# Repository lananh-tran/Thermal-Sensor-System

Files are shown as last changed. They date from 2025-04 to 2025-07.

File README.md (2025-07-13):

# Thermal Sensor System

by Lan-Anh Tran

_Many thanks to Carter Trudeau and Kyle Chen for their help in this project._

## Introduction

We are part of the [Chico Rocketry and Aerospace Club](https://www.instagram.com/chicorocketry/) at California State University, Chico. This is the documentation of one of our electronic modules for our rocket - the Wildcat V, which our team brought to [IREC 2025](https://www.herox.com/IREC2025) (International Rocket Engineering Competition). The purpose of this module is to take measurements of the surrounding ambient temperature and inner surface temperature of the rocket before and during flight for simulation purposes. The components used in this project can be viewed in the [Bill of Materials](https://github.com/lananh-tran/Thermal-Sensor-System/blob/1d724febd7ca4944d8594dc0ccbd3dcf55217213/Thermal%20Sensor%20System%20BOM%202025.xlsx) or shown below:

- [Adafruit MAX31865 PT100 RTD Temperature Sensor Amplifier](https://www.adafruit.com/product/3328)
- [Adafruit MCP9808 I2C Temperature Sensor Breakout Board](https://www.adafruit.com/product/1782)
- [MPU6050 Analog Gyro Sensors and Accelerometer Module](https://www.amazon.com/Gy-521-MPU-6050-MPU6050-Sensors-Accelerometer/dp/B008BOPN40?sr=8-2)
- [HiLetgo Micro SD TF Card Adapter Reader Module](https://www.amazon.com/HiLetgo-Adater-Interface-Conversion-Arduino/dp/B07BJ2P6X6?sr=8-1)
- [Battery Charger Module](https://www.amazon.com/dp/B098989NRZ?amp=&amp=)
- [Samsung 35E 18650 3500mAh 8A - Button Top Battery](https://www.18650batterystore.com/products/samsung-35e-button-top)
- [Arduino Nano Microcontroller](https://www.amazon.com/LAFVIN-Board-ATmega328P-Micro-Controller-Arduino/dp/B07G99NNXL?sr=8-1)
- [Surface Mount RTD PT100 Temperature Sensor](https://evosensors.com/products/p3a-tape-rec-px-1-pfxx-40-stwl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)

Link to the KiCad [schematic](https://github.com/lananh-tran/Thermal-Sensor-System/blob/4369b679e1e1e8256428873dc583f430bf157983/Thermal-System.kicad_sch) and [PCB layout](https://github.com/lananh-tran/Thermal-Sensor-System/blob/4369b679e1e1e8256428873dc583f430bf157983/Thermal-System.kicad_pcb) files.

## Design Procedure

Below is the rough design for the sensor system. See [design schematic](https://github.com/lananh-tran/Thermal-Sensor-System/blob/db7faa17b55e4ecaf4507a09ca1c67294a6be1d8/Thermal%20System%20Schematic.pdf) and [PCB layout](https://github.com/lananh-tran/Thermal-Sensor-System/blob/db7faa17b55e4ecaf4507a09ca1c67294a6be1d8/Thermal%20System%20PCB.pdf) for more details.

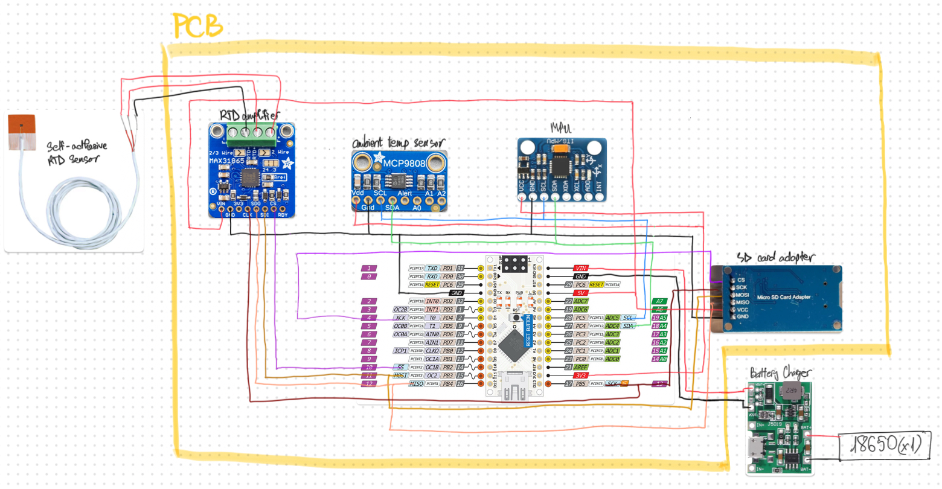
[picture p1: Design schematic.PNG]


Except for the RTD sensor, the battery charger module, and the 18650 battery, the rest are mounted on a PCB.

The MCP9808 and the MPU6050 both utilize the I2C communication protocol, while the MAX31865 and the microSD Card Adapter use the SPI protocol. Though we couldn't find a particular reason why there aren't any I2C breakout boards for the MAX31865, we assume the microSD Card Adapter has to use SPI due to its need for speed. This resulted in a communication issue, which will be discussed in the Results section.

I2C devices communicate through two lines - the clock (SCL) and the data line (SDA). An I2C master can be connected to different slaves, as long as their SDA lines are connected and their SCL lines are connected.

SPI devices require more connections, with a clock line (SCK or CLK), Master-In-Slave-Out (MISO or SDO), Master-Out-Slave-In (MOSI or SDI), and a Chip Select line (CS). Multiple SPI slaves can have their CLK, MISO, and MOSI lines connected to the corresponding lines of their master, but each slave has to be connected to a different CS pin on their master.

In order to mitigate the potential wiring errors, we opt to design and fabricate a custom PCB of size 6 x 1.6 in, with a drill hole diameter of 0.1 in. The design is done in KiCad, which is a powerful and free PCB design software. KiCad also allows 3D modelling, which is quite convenient if you want to make sure the electrical design is compatible with the mechanical structure.

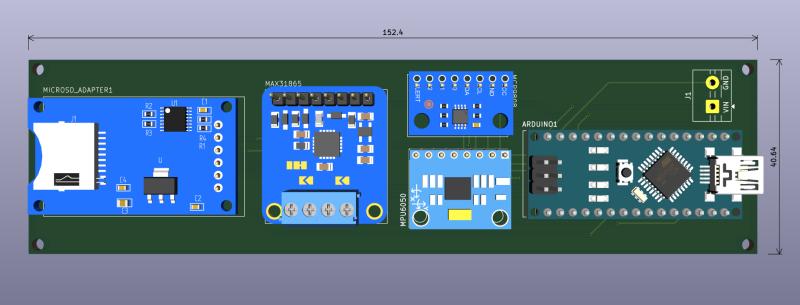
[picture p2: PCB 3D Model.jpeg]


## Assembly Process

The assembly process is quite straightforward. After soldering all the components onto the PCB, connect the RTD sensor to the MAX31865 breakout board as shown below, then connect the battery and charger module as demonstrated in the system schematic posted above.

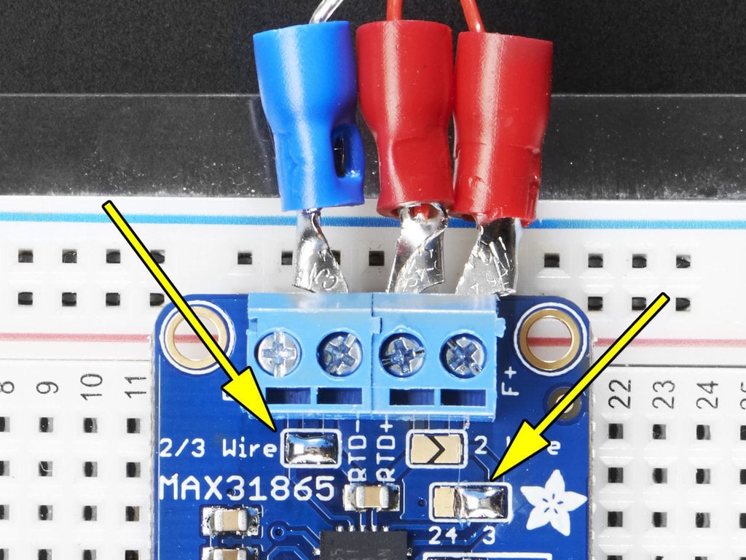
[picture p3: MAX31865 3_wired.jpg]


More details about the MAX31865 wiring can be viewed on [Adafruit's official guide](https://learn.adafruit.com/adafruit-max31865-rtd-pt100-amplifier/rtd-wiring-config).

## Results

We chose [OSH Park](https://oshpark.com/) to fabricate our PCB as they are a US-based company, thereby having a lower shipping cost.

Below is the final product before it was sent to IREC 2025 for competition:

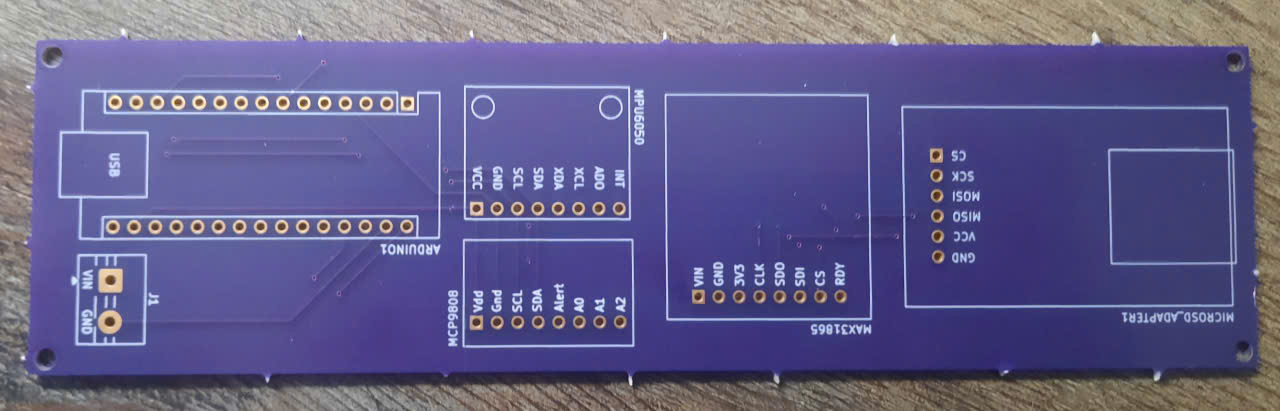
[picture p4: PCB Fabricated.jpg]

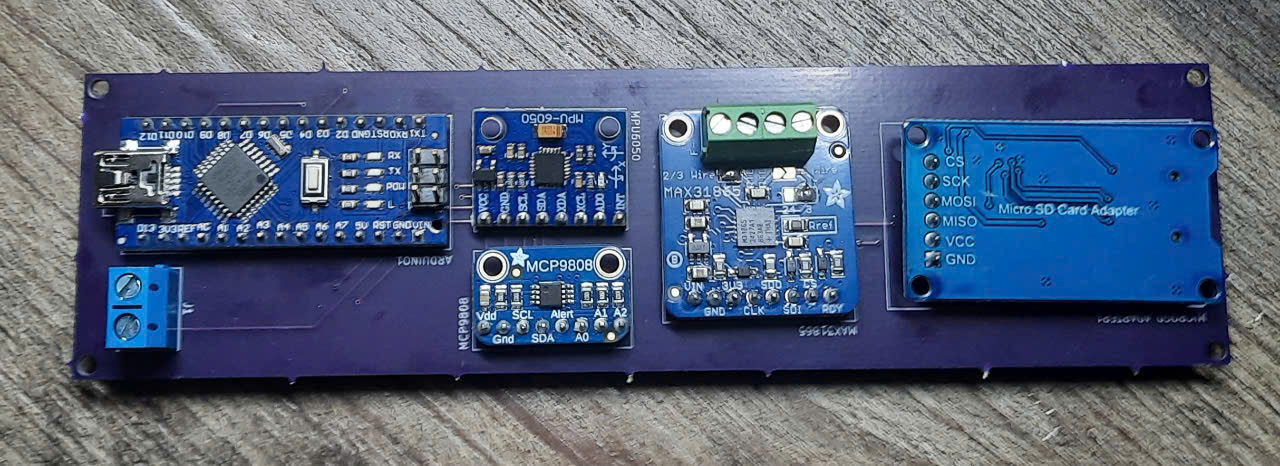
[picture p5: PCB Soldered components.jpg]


A critical issue we have with this module is the design of the microSD Adapter Module, which leads to the SPI bus not getting off the SPI bus. As a result, we initially couldn't implement multiple SPI devices using a single Arduino. To debug, we opted to utilize the logic analyzer function of the ADALM2000 module to observe the behavior of the system.

Results when the SD module is connected:
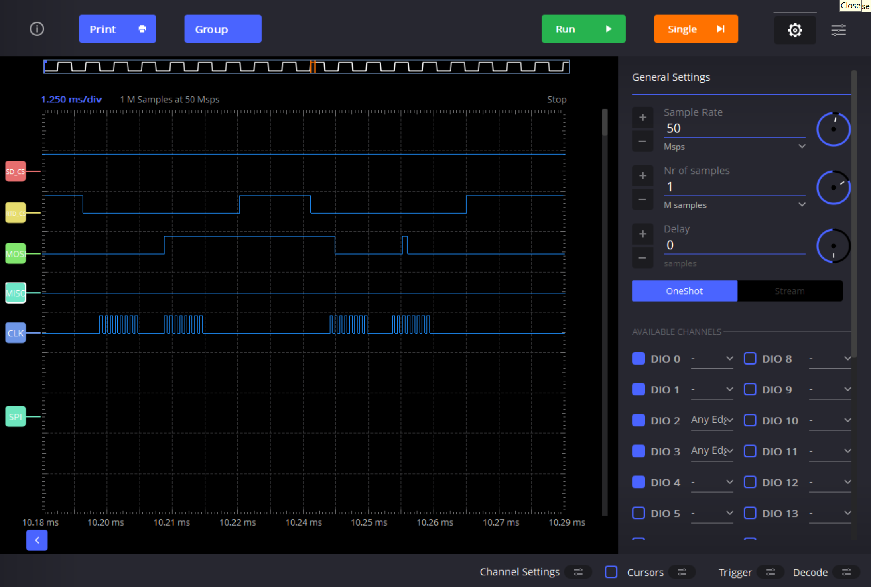
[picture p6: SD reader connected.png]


When the SD module isn't connected:
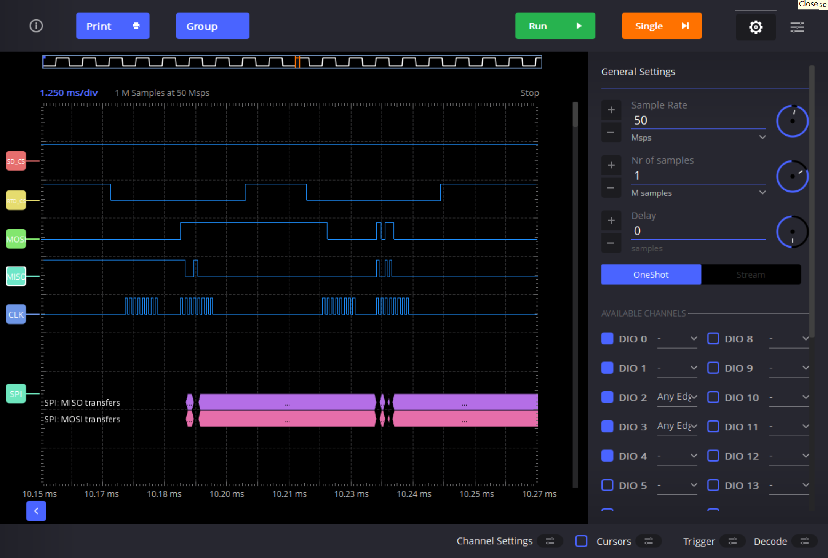
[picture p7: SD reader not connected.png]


After a close inspection of the SD module schematic, we suspect that the MISO might be pulled to GND by default by the buffer, leading to the issue with the SPI bus.
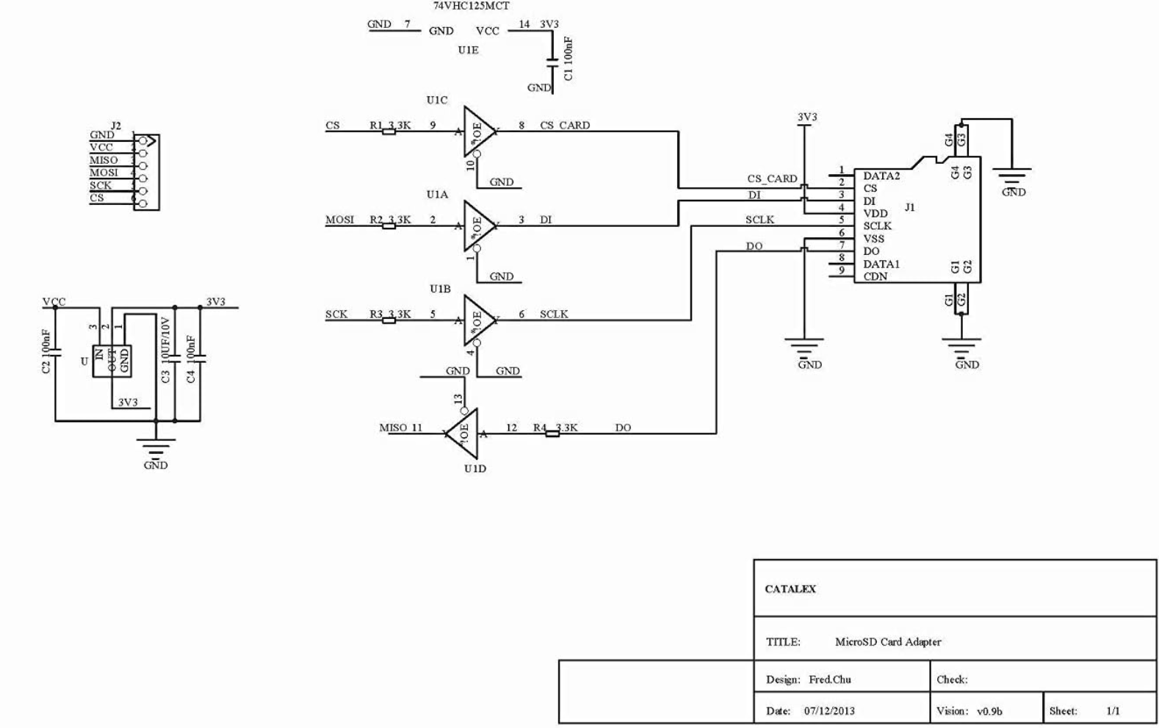
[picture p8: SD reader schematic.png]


We decided to follow a modification suggested on the Arduino Forum (source lost), as shown below.
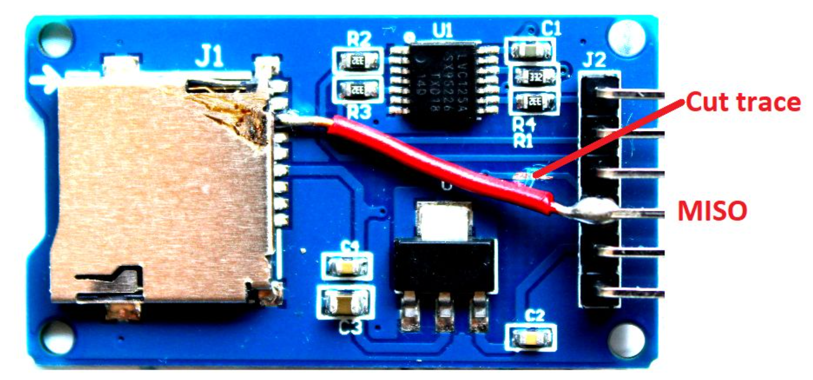
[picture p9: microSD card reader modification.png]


Our modified SD module works properly when connected to the system along with the MAX31865 amplifier.

## Code

```
#include <SPI.h>
#include <Wire.h>
#include <SD.h>
#include <Adafruit_MPU6050.h>
#include <Adafruit_Sensor.h>
#include <Adafruit_MCP9808.h>
#include <Adafruit_MAX31865.h>

// --- CONFIGURATION ---
int timeStamp = 1;
#define SD_CS 4
//SdFat SD;
File dataLog;

float acceleration;
Adafruit_MPU6050 mpu;

float ambient;
Adafruit_MCP9808 ambientTemp = Adafruit_MCP9808();

#define RREF 430.0 // Rref resistor for PT100
#define RNOMINAL 100.0 // Nominal resistance for PT100
#define RTD_CS 10
#define MOSI 11
#define MISO 12
#define CLK 13
float surface;
Adafruit_MAX31865 surfaceTemp = Adafruit_MAX31865(RTD_CS);

void setup() {
  // set serial monitor baud rate
  Serial.begin(9600);
  while(!Serial) {;}

  // MCP9808 initialization
  MCP_init();

  // MPU6050 initialization
  MPU_init();

  // SD card initialization
  SD_init();

  // MAX31865 initialization
  pinMode(RTD_CS, OUTPUT);
  digitalWrite(RTD_CS, HIGH);
  surfaceTemp.begin(MAX31865_3WIRE);
  delay(1000);

  // SPI communication setup
  SPI.begin();

  Serial.println("Begin testing:");
}

void loop() {
  // --- MCP9808 Sampling ---
  MCP_sample();

  // testing
  Serial.print("Ambient temp: "); 
  Serial.print(ambient, 3);
  Serial.println("*C");

  // --- MAX31865 Sampling ---
  MAX_sample();

  // testing
  Serial.print("Surface temp: "); 
  Serial.print(surface, 3);
  Serial.println("*C");

  // --- MPU6050 Sampling ---
  MPU_sample();

  // testing
  Serial.print("Acceleration: "); 
  Serial.print(acceleration, 3);
  Serial.println("m/s^2");

  // --- SD card reader ---
  SD_write();

  delay(1000); // take readings every 1s
}

void MCP_init(void) {
  //  A2 A1 A0 address
  //  0  0  0   0x18  this is the default address
  //  0  0  1   0x19
  //  0  1  0   0x1A
  //  0  1  1   0x1B
  //  1  0  0   0x1C
  //  1  0  1   0x1D
  //  1  1  0   0x1E
  //  1  1  1   0x1F
  if(!ambientTemp.begin(0x18)) {
	  Serial.println("Unable to connect to the MCP9808!");
	  Serial.println("Check your connections and verify the address is correct.");
	  while (1);
  }

  // Mode Resolution SampleTime
  //  0    0.5°C       30 ms
  //  1    0.25°C      65 ms
  //  2    0.125°C     130 ms
  //  3    0.0625°C    250 ms
  ambientTemp.setResolution(3);
  //Serial.println("MCP9808 initialized!");
  delay(1000); // Give sensor time to stabilize
}

void MPU_init(void) {
  if (!mpu.begin()) {
    Serial.println("Failed to find MPU6050 chip");
    while (1);
  }

  mpu.setAccelerometerRange(MPU6050_RANGE_16_G);
  mpu.setGyroRange(MPU6050_RANGE_500_DEG);
  mpu.setFilterBandwidth(MPU6050_BAND_21_HZ);

  delay(1000); // Give sensor time to stabilize
}

void SD_init(void) {
  pinMode(SD_CS, OUTPUT);
  digitalWrite(SD_CS, HIGH);
  //Serial.println("Initializing SD card...");
  if(!SD.begin(SD_CS)) {
    Serial.println("SD card initialization failed!");
    //while(1) {;}
  }
  //Serial.println("Card initialized!");

  dataLog = SD.open("DATALOG.csv", FILE_WRITE);
  if(!dataLog) {
    Serial.println("Failed to write!");
    //while(1) {;}
  }
  dataLog.println("no.,ambientTemp(C),surfaceTemp(C),acceleration(m/s^2)");
}

void MCP_sample(void) {
  ambientTemp.wake();
  delay(200);
  ambient = ambientTemp.readTempC();
  ambientTemp.shutdown_wake(1);
  delay(200);
}

void SD_write(void) {
  digitalWrite(RTD_CS, HIGH);
  digitalWrite(SD_CS, LOW);
  
  if(dataLog) {
    dataLog.print(timeStamp);
    dataLog.print(",");
    dataLog.print(ambient, 3);
    dataLog.print(",");
    dataLog.print(surface, 3);
    dataLog.print(",");
    dataLog.println(acceleration, 3);
    
    dataLog.flush();
    delay(200);
  }

  digitalWrite(SD_CS, HIGH);
  timeStamp++;
  Serial.println("Writing done");
}

void MAX_sample(void) {
  digitalWrite(SD_CS, HIGH);
  digitalWrite(RTD_CS, LOW);
  surface = surfaceTemp.temperature(RNOMINAL, RREF);
  delay(200);
  digitalWrite(RTD_CS, HIGH);
}

void MPU_sample(void) {
  // Get new sensor events with the readings
  sensors_event_t a, g, temp;
  mpu.getEvent(&a, &g, &temp);
  acceleration = sqrt(a.acceleration.x * a.acceleration.x +
                        a.acceleration.y * a.acceleration.y +
                        a.acceleration.z * a.acceleration.z) - 9.81; // account for Earth stationary acceleration
}
```

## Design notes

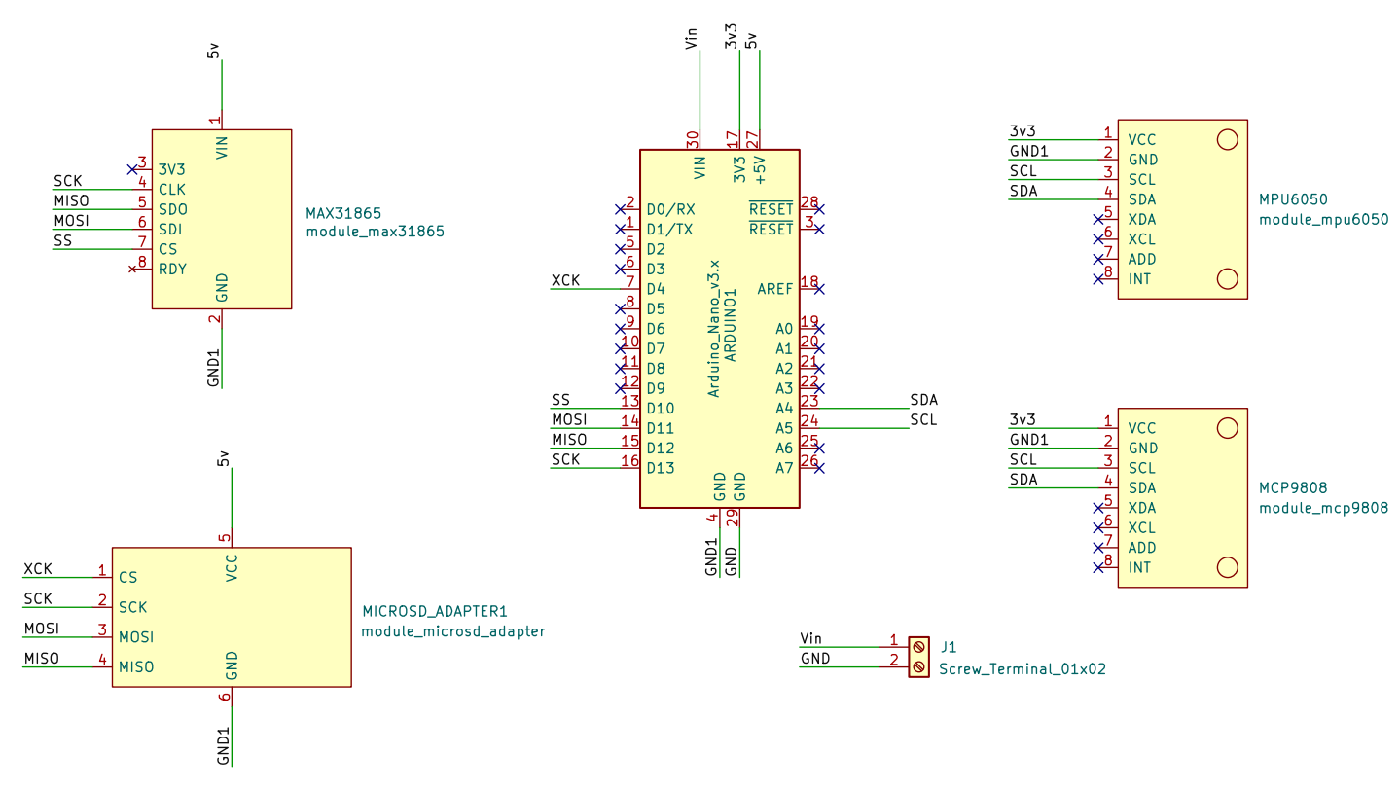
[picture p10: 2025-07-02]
KiCad Schematic.png

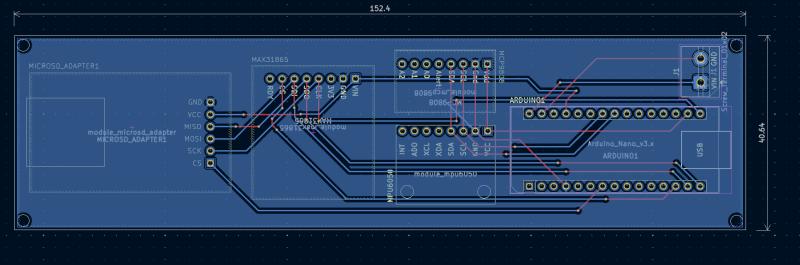
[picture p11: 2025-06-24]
PCB Layout.jpeg

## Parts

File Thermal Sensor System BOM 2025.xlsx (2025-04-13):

Website | Item | Cost per unit | Quantity | Total | Description | Link | Datasheet | Dimensions
18650 Battery Store | Samsung 35E 18650 3500mAh 8A - Button Top Battery | $9.99 | 1 | $9.99 |  | https://www.18650batterystore.com/products/samsung-35e-button-top
 |  |  | Local total | $9.99
Amazon | Battery Charger Module 6pcs | $9.89 | 1 | $9.89 |  | https://www.amazon.com/dp/B098989NRZ?ref_=cm_sw_r_cso_cp_apan_dp_P1GT6V82NTPXW35JH8QN&previewDoh=1
 | Arduino Nano 3pcs | $15.99 | 1 | $15.99 |  | https://www.amazon.com/ELEGOO-Pre-soldered-ATmega-Compatible-Arduino/dp/B0D5LYFRQP?sr=8-2 | https://www.nitrathor.com/data-sheets/arduino-nano | 43.16 mm x 17.76 mm x 2.54 mm
 | MPU-6050 Axis Accelerometer Gyroscope Sensor Module 5pcs | $14.99 | 1 | $14.99 |  | https://www.amazon.com/MPU-6050-MPU6050-Accelerometer-Gyroscope-Converter/dp/B07RXQGGJX?sr=8-18
 | Hiletgo Micro SD Card Reader Module 5pcs | $6.99 | 1 | $6.99 |  | https://www.amazon.com/HiLetgo-Adater-Interface-Conversion-Arduino/dp/B07BJ2P6X6?sr=8-1 | http://datalogger.pbworks.com/w/file/fetch/89507207/Datalogger%20-%20SD%20Memory%20Reader%20Datasheet.pdf | ‎76.2 x 58.4 x 10.2 mm
 |  |  | Local total | $47.86
Adafruit | MCP9808 Temperature Sensor Breakout Board | $4.95 | 1 | $4.95 |  | https://www.adafruit.com/product/1782 | https://cdn-shop.adafruit.com/datasheets/MCP9808.pdf | 21mm x 13mm x 2mm / 0.8" x 0.5" x 0.08
 |  |  | Local total | $4.95
Digikey | PT100 RTD Temperature Sensor Amplifier - MAX31865 | $14.95 | 1 | $14.95 |  | https://www.digikey.com/en/products/detail/adafruit-industries-llc/3328/6562952 | https://www.analog.com/media/en/technical-documentation/data-sheets/max31865.pdf | 28.0mm x 25.5mm x 3.0mm / 1.1" x 1.0" x 0.1
 |  |  | Local total | $14.95
Evolution | Surface Mount PT100 RTD Temperature Sensor | $45.00 | 1 | $45.00 |  | https://evosensors.com/products/p3a-tape-rec-px-1-pfxx-40-stwl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 | https://cdn.shopify.com/s/files/1/1679/4593/files/P3A-TAPE-REC-PX-1-PFXX-40-STWL-specsheet.pdf?v=1649167083 | 25mm x 19mm (patch)
 |  |  | Local total | $45.00
 |  |  | Grand total | $112.76

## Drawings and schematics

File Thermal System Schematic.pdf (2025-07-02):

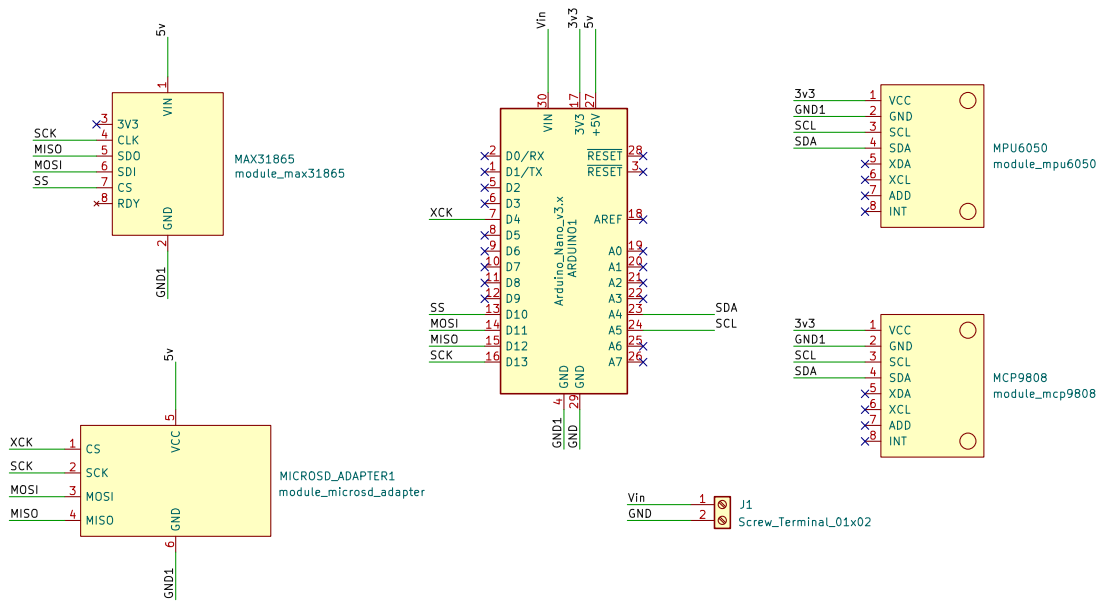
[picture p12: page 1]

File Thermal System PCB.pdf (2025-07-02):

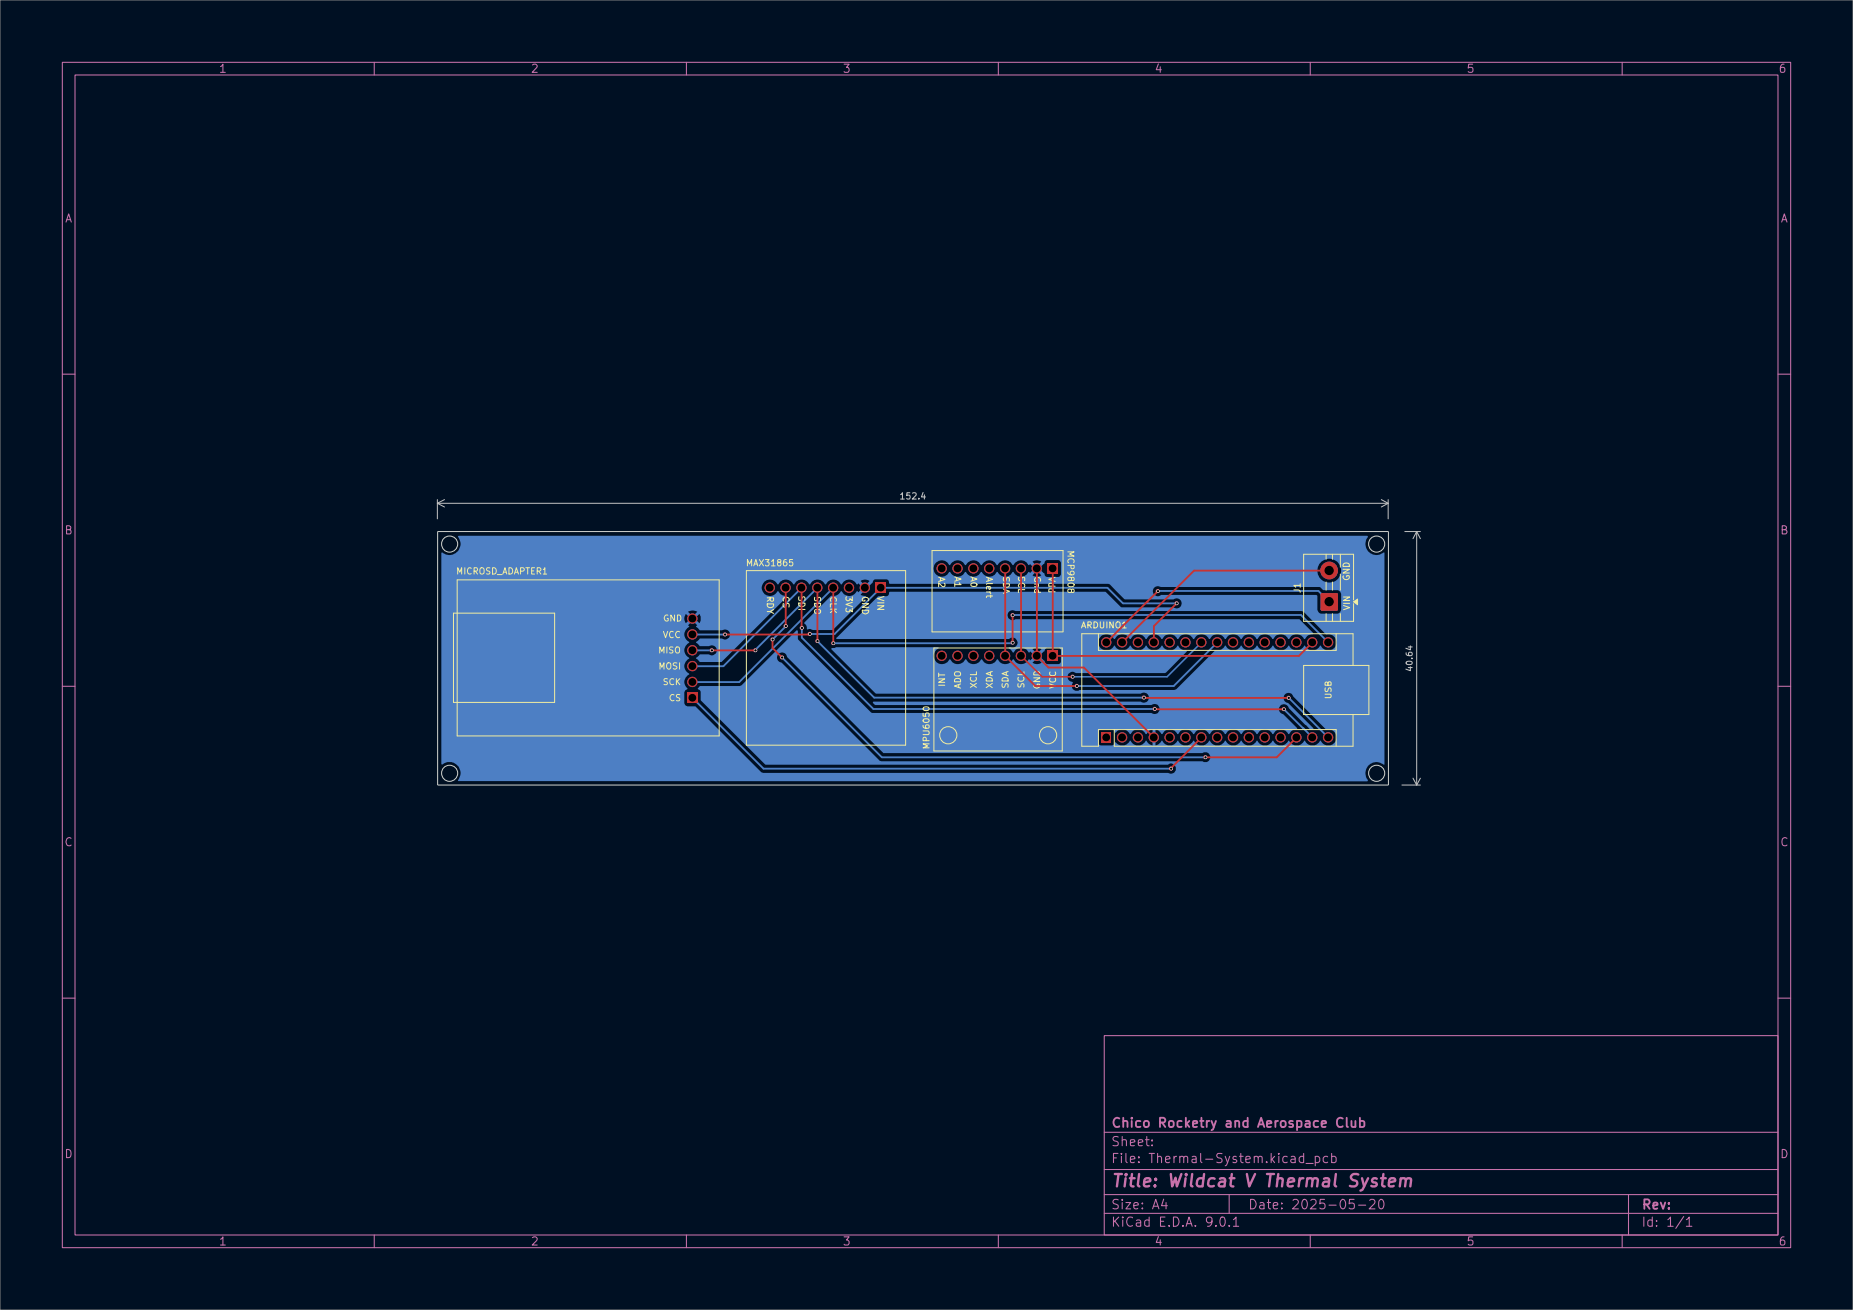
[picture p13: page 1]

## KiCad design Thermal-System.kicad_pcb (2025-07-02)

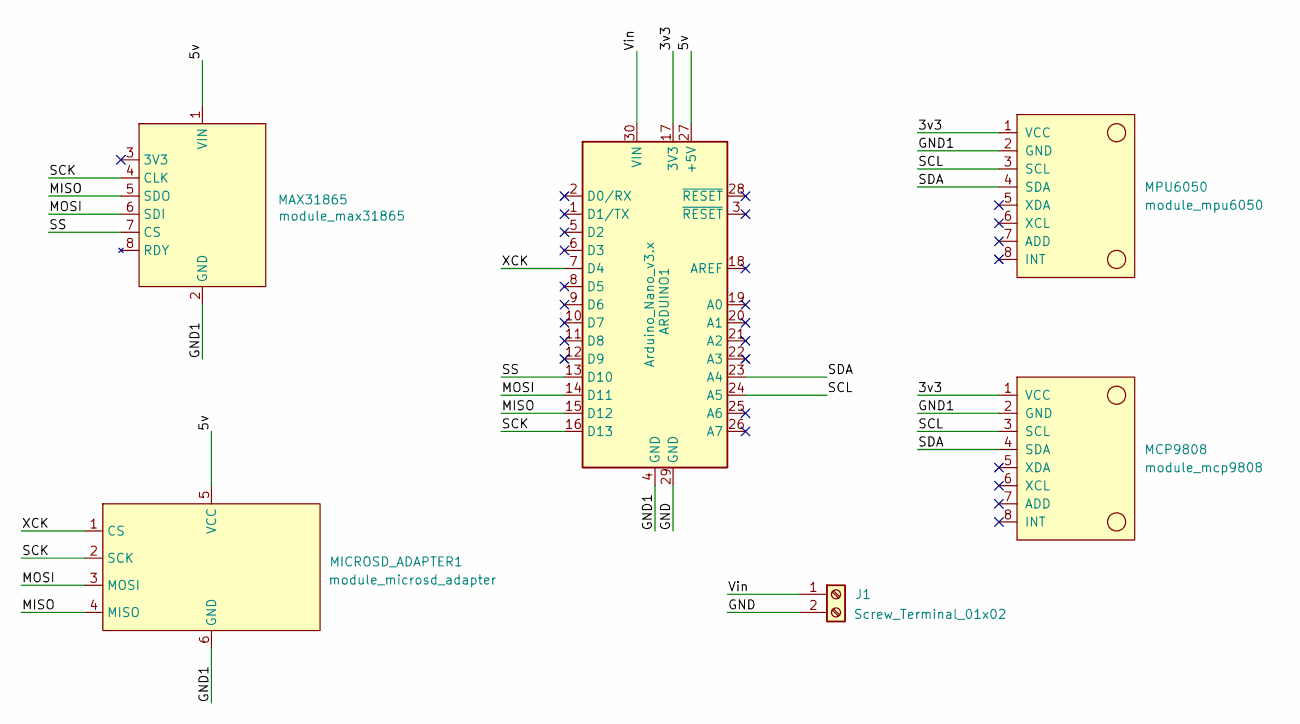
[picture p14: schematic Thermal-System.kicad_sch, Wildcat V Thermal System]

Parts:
ARDUINO1: Arduino_Nano_v3.x; Arduino_Nano
J1: Screw_Terminal_01x02; TerminalBlock_MaiXu_MX126-5.0-02P_1x02_P5.00mm
MAX31865: module_max31865
MCP9808: module_mcp9808
MICROSD_ADAPTER1: module_microsd_adapter; module_microsdadapter
MPU6050: module_mpu6050

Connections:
/3v3: ARDUINO1.17 (3V3), MCP9808.1 (VCC), MPU6050.1 (VCC)
/5v: ARDUINO1.27 (+5V), MAX31865.1 (VIN), MICROSD_ADAPTER1.5 (VCC)
/GND: ARDUINO1.29 (GND), J1.2
/GND1: ARDUINO1.4 (GND), MAX31865.2 (GND), MCP9808.2 (GND), MICROSD_ADAPTER1.6 (GND), MPU6050.2 (GND)
/MISO: ARDUINO1.15 (D12), MAX31865.5 (SDO), MICROSD_ADAPTER1.4 (MISO)
/MOSI: ARDUINO1.14 (D11), MAX31865.6 (SDI), MICROSD_ADAPTER1.3 (MOSI)
/SCK: ARDUINO1.16 (D13), MAX31865.4 (CLK), MICROSD_ADAPTER1.2 (SCK)
/SCL: ARDUINO1.24 (A5), MCP9808.3 (SCL), MPU6050.3 (SCL)
/SDA: ARDUINO1.23 (A4), MCP9808.4 (SDA), MPU6050.4 (SDA)
/SS: ARDUINO1.13 (D10), MAX31865.7 (CS)
/Vin: ARDUINO1.30 (VIN), J1.1
/XCK: ARDUINO1.7 (D4), MICROSD_ADAPTER1.1 (CS)

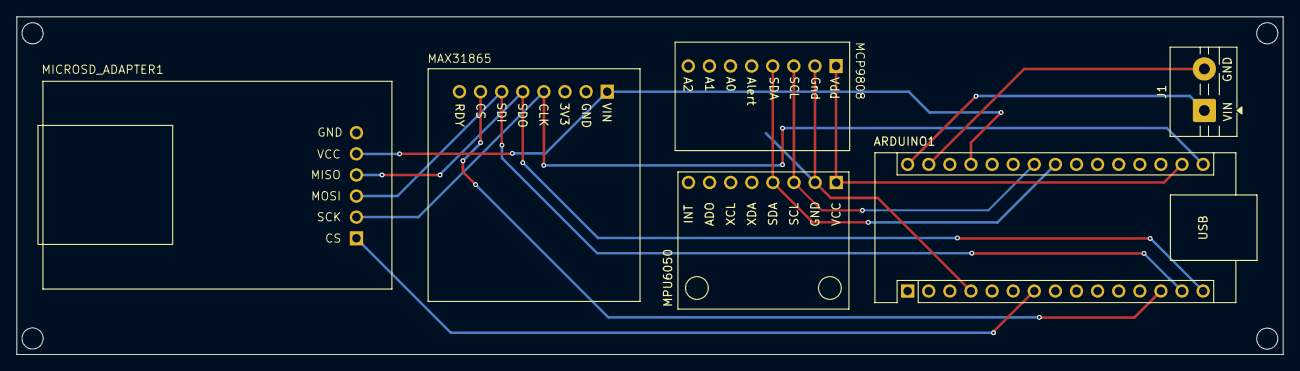
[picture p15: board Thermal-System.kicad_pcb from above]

Board: 2 copper layers, 152.4 x 40.6 mm, 6 parts (0 on the bottom side), 12 nets.

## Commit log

2025-04-11 add parts list and dimensions
    [Thermal Sensor BOM 2025.xlsx]
2025-04-12 edit datasheets
    [Thermal Sensor BOM 2025.xlsx]
2025-04-13 add batteries & MPU
    [Thermal Sensor BOM 2025.xlsx, Thermal Sensor System BOM 2025.xlsx]
2025-04-13 add battery + charger module & replace RTC with MPU
2025-06-24 upload schematic
2025-07-02 Rename Screenshot 2025-07-01 221512.png to KiCad Schematic
2025-07-02 Rename KiCad Schematic to KiCad Schematic.png
2025-07-02 upload KiCad files
    [Thermal-System.kicad_pcb, Thermal-System.kicad_sch]
